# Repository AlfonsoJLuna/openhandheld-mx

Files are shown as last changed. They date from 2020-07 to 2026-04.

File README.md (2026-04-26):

# OpenHandheld MX

Open-source development board in the shape of a handheld game console.

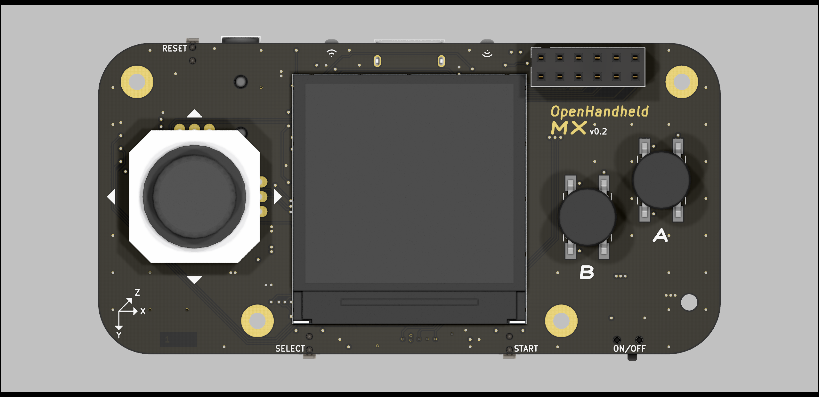
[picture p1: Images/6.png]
OpenHandheld MX (Front)
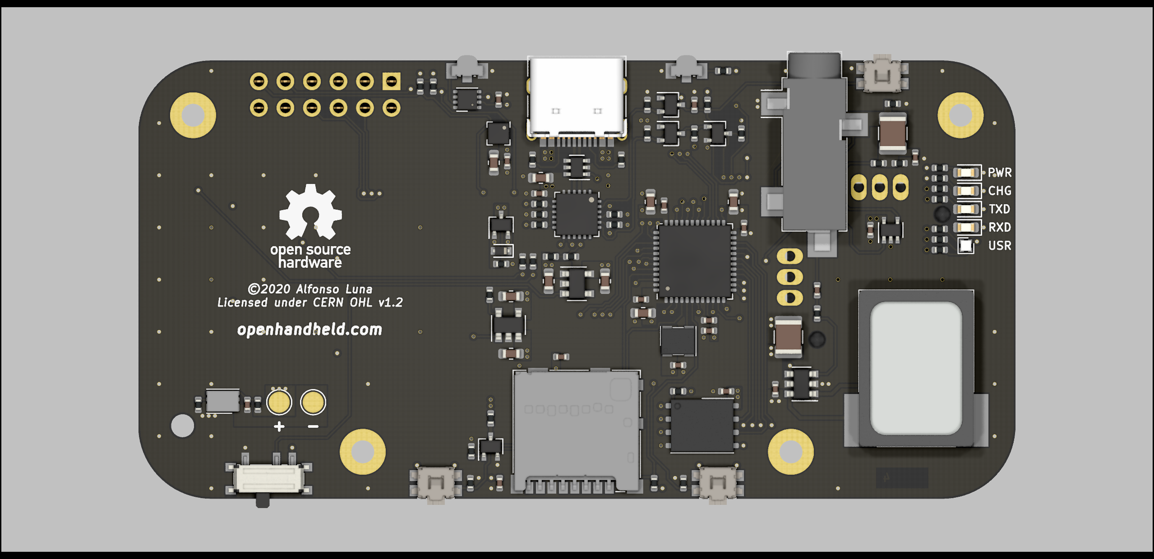
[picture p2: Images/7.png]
OpenHandheld MX (Back)
 | 
:---: | :---:
Front | Back

## Related repositories

Example code for this board can be found in [openhandheld-mx-sdk](https://github.com/AlfonsoJLuna/openhandheld-mx-sdk).

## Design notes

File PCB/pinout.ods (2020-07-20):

Número | Name | Header | Board | ADC | DAC | AF1/IR (TIM) | AF2 (TIM) | AF3 (USART2) | AF4 (I2C) | AF5 (SPI) | AF6 (SPI3) | AF7 (USARTS) | AF9 (CAN) | AF10 (QSPI) | AF14 (TIMS)
10 | PA0 | - | ADC VCC_DET | ADC1_IN5 |  | TIM2_CH1 | - | - | - | - | - | USART2_CTS | - | - | TIM2_ETR
11 | PA1 | - | LED B | ADC1_IN6 |  | TIM2_CH2 | - | - | I2C1_SMBA | SPI1_SCK | - | USART2_RTS_ DE | - | - | TIM15_CH1N
12 | PA2 | GPIO / ADC / USART2_TX | - | ADC1_IN7 |  | TIM2_CH3 | - | - | - | - | - | USART2_TX | - | QUADSPI_ BK1_NCS | TIM15_CH1
13 | PA3 | - | ADC JOY_Y | ADC1_IN8 |  | TIM2_CH4 | - | - | - | - | - | USART2_RX | - | QUADSPI_CLK | TIM15_CH2
14 | PA4 | - | ADC JOY_X | ADC1_IN9 | DAC1_OUT1 | - | - | - | - | SPI1_NSS | SPI3_NSS | USART2_CK | - | - | LPTIM2_OUT
15 | PA5 | - | AUDIO OUT | ADC1_IN10 | DAC1_OUT2 | TIM2_CH1 | TIM2_ETR | - | - | SPI1_SCK | - | - | - | - | LPTIM2_ETR
l | PA6 | - | QSPI_IO3 | ADC1_IN11 |  | TIM1_BKIN | - | - | - | SPI1_MISO | COMP1_OUT | USART3_CTS | - | QUADSPI_ BK1_IO3 | TIM16_CH1
17 | PA7 | - | QSPI_IO2 | ADC1_IN12 |  | TIM1_CH1N | - | - | I2C3_SCL | SPI1_MOSI | - | - | - | QUADSPI_ BK1_IO2 | -
29 | PA8 | - | LED R |  |  | TIM1_CH1 | - | - | - | - | - | USART1_CK | - | - | LPTIM2_OUT
30 | PA9 | - | USART1_TX |  |  | TIM1_CH2 | - | - | I2C1_SCL | - | - | USART1_TX | - | - | TIM15_BKIN
31 | PA10 | - | USART1_RX |  |  | TIM1_CH3 | - | - | I2C1_SDA | - | - | USART1_RX | - | - | -
32 | PA11 | - | LED G |  |  | TIM1_CH4 | TIM1_BKIN2 | - | - | SPI1_MISO | COMP1_OUT | USART1_CTS | CAN1_RX | - | -
33 | PA12 | - | LCD DATA/CMD |  |  | TIM1_ETR | - | - | - | SPI1_MOSI | - | USART1_RTS_DE | CAN1_TX | - | -
34 | PA13 (pull-up reset) | GPIO / SWDIO | - |  |  | IR_OUT | - | - | - | - | - | - | - | - | -
37 | PA14 (pull-down reset) | GPIO / SWCLK | - |  |  | LPTIM1_OUT | - | - | I2C1_SMBA | - | - | - | - | - | -
38 | PA15 (pull-up reset) | GPIO / USART2_RX | - |  |  | TIM2_CH1 | TIM2_ETR | USART2_RX | - | SPI1_NSS | SPI3_NSS | USART3_RTS_ DE | TSC_G3_IO1 |  | -
18 | PB0 | - | QSPI_IO1 | ADC1_IN15 |  | TIM1_CH2N | - | - | - | SPI1_NSS | - | USART3_CK | - | QUADSPI_ BK1_IO1 | -
19 | PB1 | - | QSPI_IO0 | ADC1_IN16 |  | TIM1_CH3N | - | - | - | - | - | USART3_RTS_DE | - | QUADSPI_ BK1_IO0 | LPTIM2_IN1
20 | PB2 | - | IR_IN |  |  | LPTIM1_OUT | - | - | I2C3_SMBA | - | - | - | - | - | -
39 | PB3 | - | LCD SCK |  |  | TIM2_CH2 | - | - | - | SPI1_SCK | SPI3_SCK | USART1_RTS_ DE | - | - | -
40 | PB4 (pull-up reset) | - | LCD RESET |  |  | - | - | - | I2C3_SDA | SPI1_MISO | SPI3_MISO | USART1_CTS | TSC_G2_IO1 | - | -
41 | PB5 | - | LCD MOSI |  |  | LPTIM1_IN1 | - | - | I2C1_SMBA | SPI1_MOSI | SPI3_MOSI | USART1_CK | TSC_G2_IO2 | - | TIM16_BKIN
42 | PB6 | I2C1_SCL | I2C1_SCL |  |  | LPTIM1_ETR | - | - | I2C1_SCL | - | - | USART1_TX | TSC_G2_IO3 | - | TIM16_CH1N
43 | PB7 | I2C1_SDA | I2C1_SDA |  |  | LPTIM1_IN2 | - | - | I2C1_SDA | - | - | USART1_RX | TSC_G2_IO4 | - | -
45 | PB8 | - | LCD LIGHT |  |  | - | - | - | I2C1_SCL | - | - | - | CAN1_RX | - | TIM16_CH1
46 | PB9 | - | IR_OUT |  |  | IR_OUT | - | - | I2C1_SDA | SPI2_NSS | - | - | CAN1_TX | - | -
21 | PB10 | - | QSPI_CLK |  |  | TIM2_CH3 | - | - | I2C2_SCL | SPI2_SCK | - | USART3_TX | TSC_SYNC | QUADSPI_CLK | -
22 | PB11 | - | QSPI_NCS |  |  | TIM2_CH4 | - | - | I2C2_SDA | - | - | USART3_RX | - | QUADSPI_ BK1_NCS | -
25 | PB12 |  | microSD CS |  |  | TIM1_BKIN | - | TIM1_BKIN_ COMP2 | I2C2_SMBA | SPI2_NSS | - | USART3_CK | TSC_G1_IO1 | - | TIM15_BKIN
26 | PB13 | SPI2_SCK | microSD SCK |  |  | TIM1_CH1N | - | - | I2C2_SCL | SPI2_SCK | - | USART3_CTS | TSC_G1_IO2 | - | TIM15_CH1N
27 | PB14 | SPI2_MISO | microSD MISO |  |  | TIM1_CH2N | - | - | I2C2_SDA | SPI2_MISO | - | USART3_RTS_ DE | TSC_G1_IO3 | - | TIM15_CH1
28 | PB15 | SPI2_MOSI | microSD MOSI |  |  | TIM1_CH3N | - | - | - | SPI2_MOSI | - | - | TSC_G1_IO4 | - | TIM15_CH2
2 | PC13 | - | B
3 | PC14-OSC32_IN | - | A
4 | PC15-OSC32_OUT | - | START
6 | PH1-OSC_OUT | - | SELECT
1 | VBAT
5 | PH0-OSC_IN
7 | NRST | RESET | RESET
8 | VSSA/VREF-
9 | VDDA/VREF+
23 | GND
24 | VDD
35 | GND
36 | VDD | 3V3
44 | PH3/BOOT0 |  | BOOT0
47 | GND | GND
48 | VDD
49 | PAD

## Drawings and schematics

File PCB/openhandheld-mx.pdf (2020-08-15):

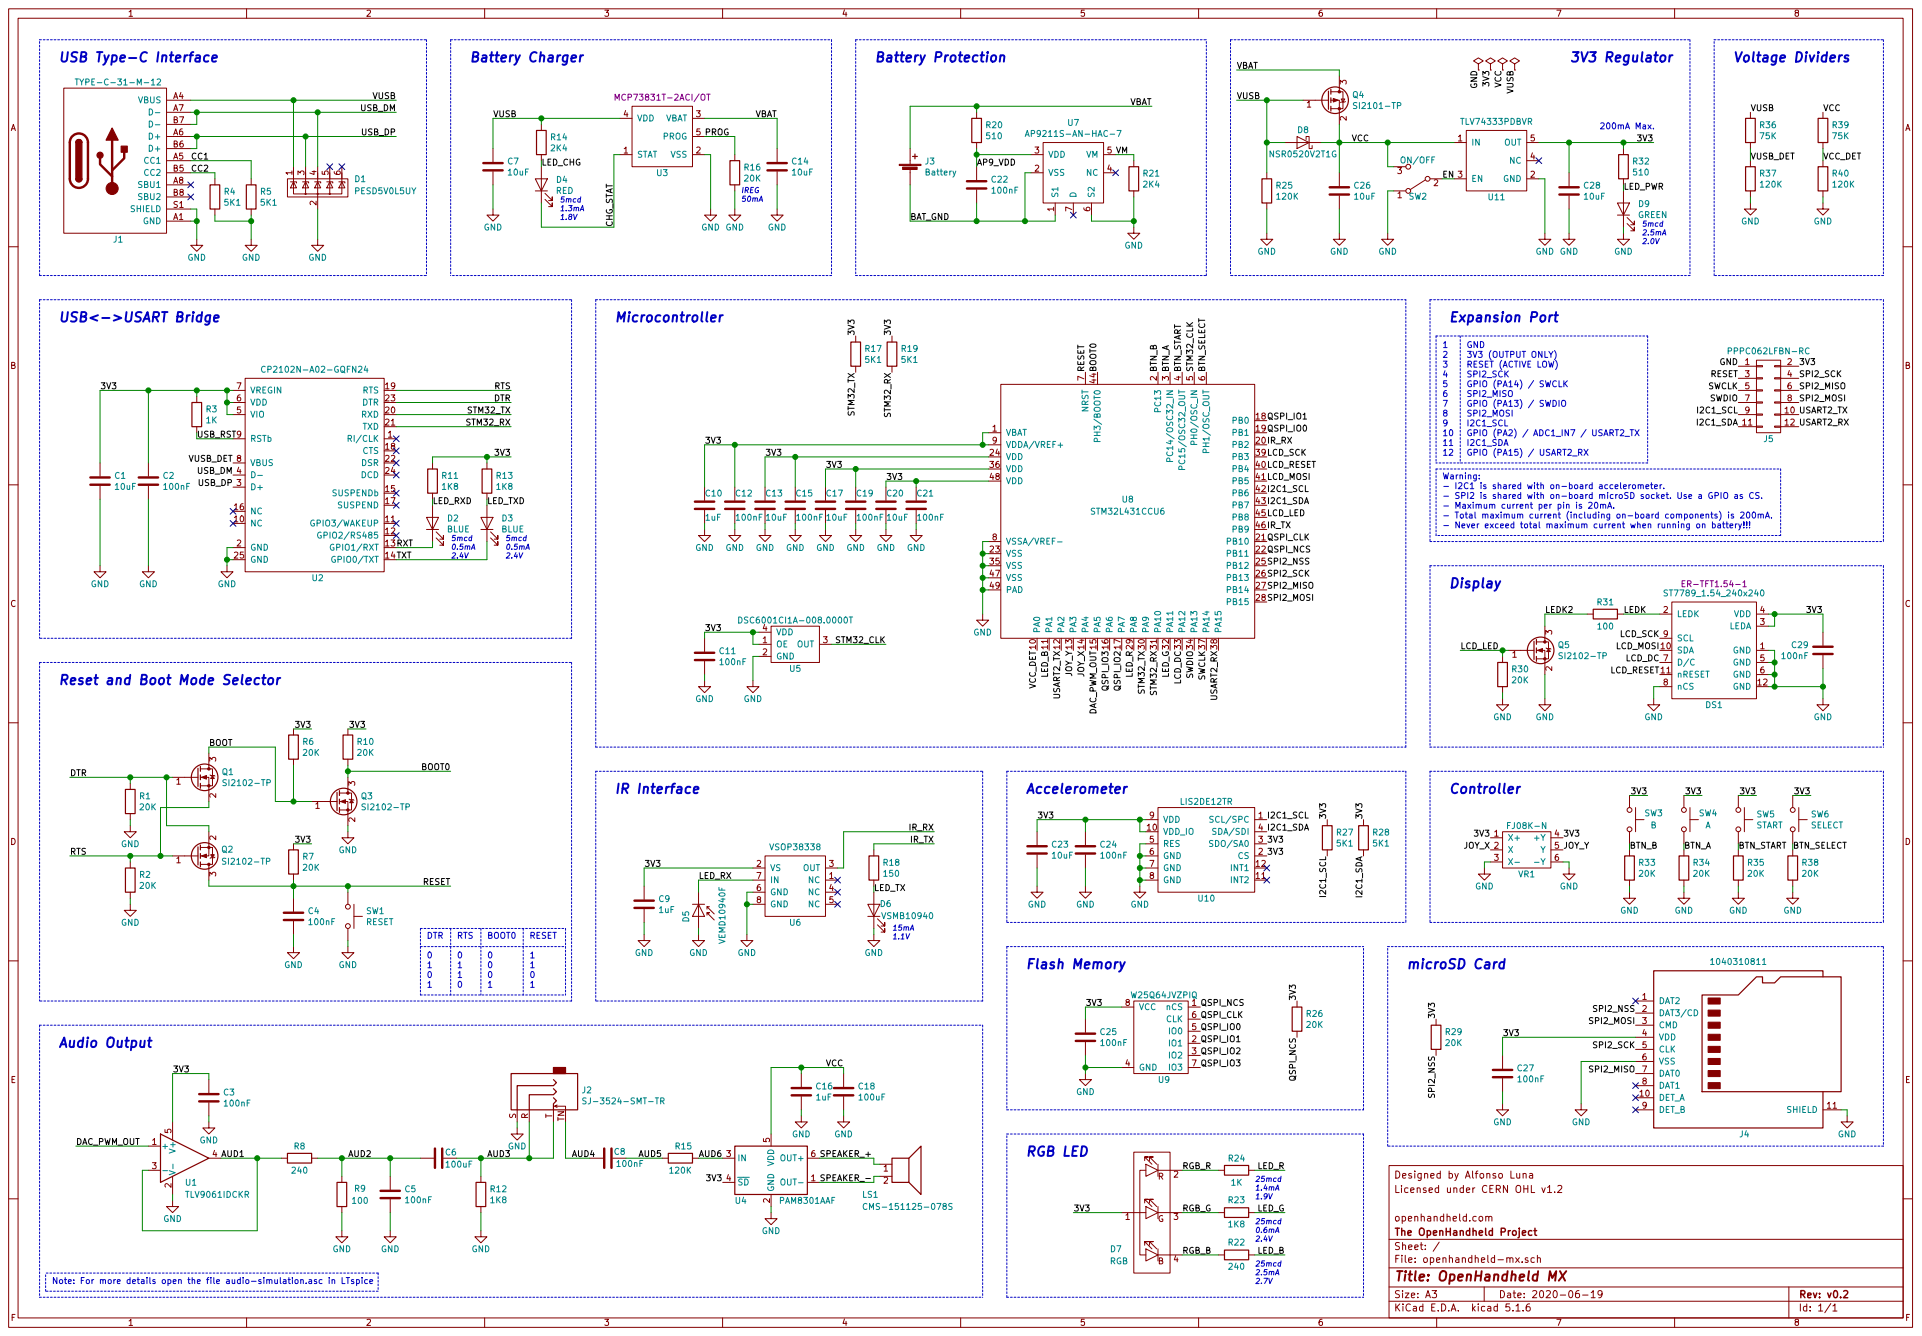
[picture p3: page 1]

200mA Max. Reset and Boot Mode Selector

1 VSS 2 VDD 3 NC 4 VM 5 S2

Expansion Port 1

- Never exceed total maximum current when running on battery!!! GND

2 3 4 5 6 7 8 9 10 11 | 3V3 (OUTPUT ONLY) RESET (ACTIVE LOW) SPI2_SCK GPIO (PA14) / SWCLK SPI2_MISO GPIO (PA13) / SWDIO SPI2_MOSI I2C1_SCL GPIO (PA2) / ADC1_IN7 / USART2_TX I2C1_SDA GPIO (PA15) / USART2_RX

7 VSSA/VREF- 8 VDDA/VREF+ 9 U8 STM32L431CCU6 C11

12Warning: - I2C1 is shared with on-board accelerometer. - SPI2 is shared with on-board microSD socket. Use a GPIO as CS. - Maximum current per pin is 20mA.

- Total maximum current (including on-board components) is 200mA.

Licensed under CERN OHL v1.2 Designed by Alfonso Luna

openhandheld.com
File: openhandheld-mx.sch Sheet: / The OpenHandheld Project

Id: 1/1 Title: OpenHandheld MX

Note: For more details open the file audio-simulation.asc in LTspice

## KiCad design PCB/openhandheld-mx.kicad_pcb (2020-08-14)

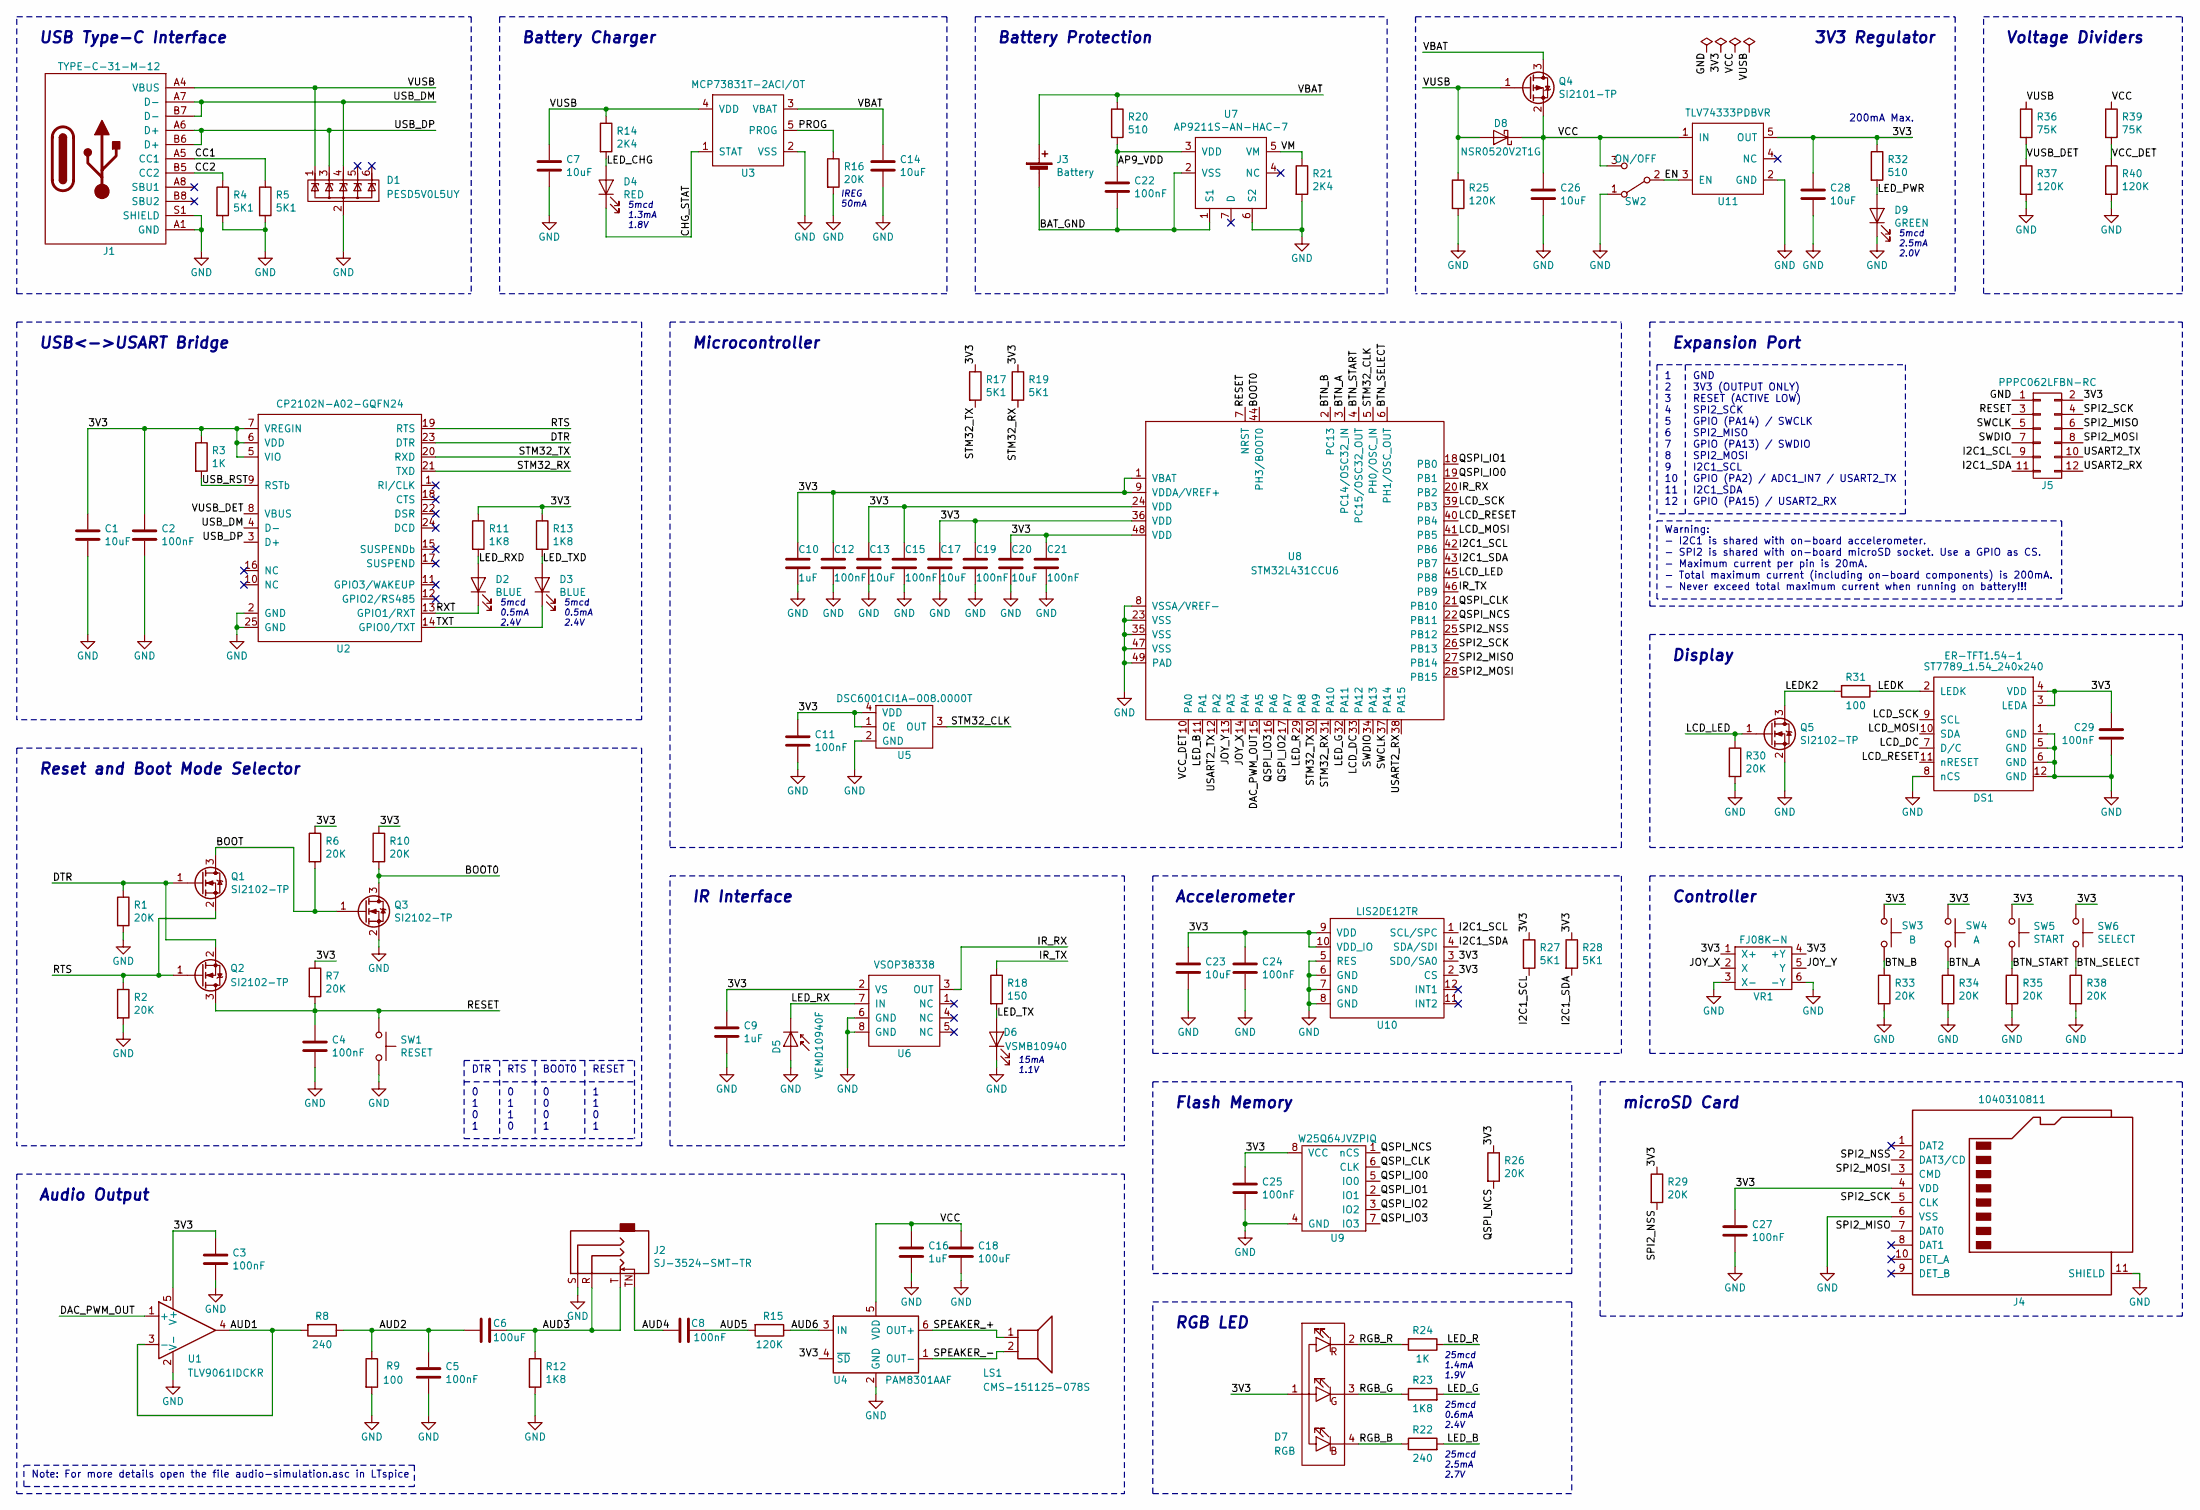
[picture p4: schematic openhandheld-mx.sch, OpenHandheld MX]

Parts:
C1, C7, C13, C14, C17, C20, C23, C26, C28: 10uF; C_0603_1608Metric; MPN CL10A106KP8NNNC
C2, C3, C4, C5, C8, C11, C12, C15, C19, C21, C22, C24, C25, C27, C29: 100nF; C_0402_1005Metric; MPN CL05B104KO5NNNC
C6, C18: 100uF; C_1210_3225Metric; MPN CL32A107MQVNNNE
C9, C10, C16: 1uF; C_0402_1005Metric; MPN CL05A105KO5NNNC
D1: PESD5V0L5UY; SOT-363_SC-70-6; MPN PESD5V0L5UY
D2, D3: BLUE; LED_0603_1608Metric; MPN 150060BS75000
D4: RED; LED_0603_1608Metric; MPN 150060SS75000
D5: VEMD10940F; Vishay_IR; MPN VEMD10940F
D6: VSMB10940; Vishay_IR; MPN VSMB10940
D7: RGB; 150044M155260; MPN 150044M155260
D8: NSR0520V2T1G; D_SOD-523; MPN NSR0520V2T1G
D9: GREEN; LED_0603_1608Metric; MPN 150060VS75000
DS1: ST7789_1.54_240x240; MPN ER-TFT1.54-1
J1: TYPE-C-31-M-12; MPN TYPE-C-31-M-12
J2: SJ-3524-SMT-TR; MPN SJ-3524-SMT-TR
J3: Battery; Solder_Pad_D2
J4: 1040310811; MPN 1040310811
J5: PPPC062LFBN-RC; PinSocket_2x06_P2.54mm_Vertical; MPN PPPC062LFBN-RC
LS1: CMS-151125-078S; Speaker_15x11mm; MPN CMS-151125-078S
Q1, Q2, Q3, Q5: SI2102-TP; SOT-323_SC-70; MPN SI2102-TP
Q4: SI2101-TP; SOT-323_SC-70; MPN SI2101-TP
R1, R2, R6, R7, R10, R16, R26, R29, R30, R33, R34, R35, R38: 20K; R_0402_1005Metric; MPN RC0402FR-0720KL
R3, R24: 1K; R_0402_1005Metric; MPN RC0402FR-071KL
R4, R5, R17, R19, R27, R28: 5K1; R_0402_1005Metric; MPN RC0402FR-075K1L
R8, R22: 240; R_0402_1005Metric; MPN RC0402FR-07240RL
R9, R31: 100; R_0402_1005Metric; MPN RC0402FR-07100RL
R11, R12, R13, R23: 1K8; R_0402_1005Metric; MPN RC0402FR-071K8L
R14, R21: 2K4; R_0402_1005Metric; MPN RC0402FR-072K4L
R15, R25, R37, R40: 120K; R_0402_1005Metric; MPN RC0402FR-07120KL
R18: 150; R_0402_1005Metric; MPN RC0402FR-07150RL
R20, R32: 510; R_0402_1005Metric; MPN RC0402FR-07510RL
R36, R39: 75K; R_0402_1005Metric; MPN RC0402FR-0775KL
SW1: RESET; EVQP7; MPN EVQ-P7L01P
SW2: ON/OFF; CUS-12TB; MPN CUS-12TB
SW3: B; TL3301TF160QG; MPN TL3301TF160QG
SW4: A; TL3301TF160QG; MPN TL3301TF160QG
SW5: START; EVQP7; MPN EVQ-P7L01P
SW6: SELECT; EVQP7; MPN EVQ-P7L01P
U1: TLV9061IDCKR; SOT-353_SC-70-5; MPN TLV9061IDCKR
U2: CP2102N-A02-GQFN24; QFN-24-1EP_4x4mm_P0.5mm_EP2.6x2.6mm; MPN CP2102N-A02-GQFN24
U3: MCP73831T-2ACI_OT; SOT-23-5; MPN MCP73831T-2ACI/OT
U4: PAM8301AAF; SOT-23-6; MPN PAM8301AAF
U5: DSC6001CI1A-008.0000T; DSC60XX-3.2x2.5; MPN DSC6001CI1A-008.0000T
U6: VSOP38338; MPN VSOP38338
U7: AP9211S-AN-HAC-7; MPN AP9211S-AN-HAC-7
U8: STM32L431CCU6; STM32-UFQFPN48; MPN STM32L431CCU6
U9: W25Q64JVZPIQ; Winbond_WSON8_6x5mm; MPN W25Q64JVZPIQ
U10: LIS2DE12TR; MPN LIS2DE12TR
U11: TLV74333PDBVR; SOT-23-5; MPN TLV74333PDBVR
VR1: FJ08K-N; MPN FJ08K-N

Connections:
/3V3: C1.1, C2.1, C3.1, C9.1, C10.1, C11.1, C12.1, C13.1, C15.1, C17.1, C19.1, C20.1, C21.1, C23.1, C24.1, C25.1, C27.1, C28.1, C29.1, D7.1 (A), DS1.3 (LEDA), DS1.4 (VDD), J4.4 (VDD), J5.2, R3.1, R6.1, R7.1, R10.1, R11.1, R13.1, R17.1, R19.1, R26.1, R27.1, R28.1, R29.1, R32.1, SW3.2, SW4.2, SW5.1, SW6.1, U1.5 (V+), U2.5 (VIO), U2.6 (VDD), U2.7 (VREGIN), U4.4 (~SD), U5.1 (OE), U5.4 (VDD), U6.2 (VS), U8.1 (VBAT), U8.9 (VDDA/VREF+), U8.24 (VDD), U8.36 (VDD), U8.48 (VDD), U9.8 (VCC), U10.2 (CS), U10.3 (SDO/SA0), U10.9 (VDD), U10.10 (VDD_IO), U11.5 (OUT), VR1.1 (X+), VR1.4 (+Y)
/AP9_VDD: C22.1, R20.2, U7.3 (VDD)
/AUD1: R8.2, U1.3 (-), U1.4
/AUD2: C5.1, C6.2, R8.1, R9.1
/AUD3: C6.1, J2.R, J2.T, R12.1
/AUD4: C8.1, J2.TN
/AUD5: C8.2, R15.2
/AUD6: R15.1, U4.3 (IN)
/BAT_GND: C22.2, J3.2 (-), U7.1 (S1), U7.2 (VSS)
/BOOT: Q1.3 (D), Q3.1 (G), R6.2
/BOOT0: Q3.3 (D), R10.2, U8.44 (PH3/BOOT0)
/BTN_A: R34.1, SW4.1, U8.3 (PC14/OSC32_IN)
/BTN_B: R33.1, SW3.1, U8.2 (PC13)
/BTN_SELECT: R38.1, SW6.2, U8.6 (PH1/OSC_OUT)
/BTN_START: R35.1, SW5.2, U8.4 (PC15/OSC32_OUT)
/CC1: J1.A5 (CC1), R5.1
/CC2: J1.B5 (CC2), R4.1
/CHG_STAT: D4.1 (K), U3.1 (STAT)
/DAC_PWM_OUT: U1.1 (+), U8.15 (PA5)
/DTR: Q1.1 (G), Q2.2 (S), R1.1, U2.23 (DTR)
/EN: SW2.2 (B), U11.3 (EN)
/I2C1_SCL: J5.9, R27.2, U8.42 (PB6), U10.1 (SCL/SPC)
/I2C1_SDA: J5.11, R28.2, U8.43 (PB7), U10.4 (SDA/SDI)
/IR_RX: U6.3 (OUT), U8.20 (PB2)
/IR_TX: R18.1, U8.46 (PB9)
/JOY_X: U8.14 (PA4), VR1.2 (X)
/JOY_Y: U8.13 (PA3), VR1.5 (Y)
/LCD_DC: DS1.7 (D/C), U8.33 (PA12)
/LCD_LED: Q5.1 (G), R30.1, U8.45 (PB8)
/LCD_MOSI: DS1.10 (SDA), U8.41 (PB5)
/LCD_RESET: DS1.11 (nRESET), U8.40 (PB4)
/LCD_SCK: DS1.9 (SCL), U8.39 (PB3)
/LEDK: DS1.2 (LEDK), R31.1
/LEDK2: Q5.3 (D), R31.2
/LED_B: R22.2, U8.11 (PA1)
/LED_CHG: D4.2 (A), R14.2
/LED_G: R23.2, U8.32 (PA11)
/LED_PWR: D9.2 (A), R32.2
/LED_R: R24.1, U8.29 (PA8)
/LED_RX: D5.1 (K), U6.7 (IN)
/LED_RXD: D2.2 (A), R11.2
/LED_TX: D6.2 (A), R18.2
/LED_TXD: D3.2 (A), R13.2
/PROG: R16.1, U3.5 (PROG)
/QSPI_CLK: U8.21 (PB10), U9.6 (CLK)
/QSPI_IO0: U8.19 (PB1), U9.5 (IO0)
/QSPI_IO1: U8.18 (PB0), U9.2 (IO1)
/QSPI_IO2: U8.17 (PA7), U9.3 (IO2)
/QSPI_IO3: U8.16 (PA6), U9.7 (IO3)
/QSPI_NCS: R26.2, U8.22 (PB11), U9.1 (nCS)
/RESET: C4.1, J5.3, Q2.3 (D), R7.2, SW1.1, U8.7 (NRST)
/RGB_B: D7.4 (BK), R22.1
/RGB_G: D7.3 (GK), R23.1
/RGB_R: D7.2 (RK), R24.2
/RTS: Q1.2 (S), Q2.1 (G), R2.1, U2.19 (RTS)
/RXT: D2.1 (K), U2.13 (GPIO1/RXT)
/SPEAKER_+: LS1.1, U4.6 (OUT+)
/SPEAKER_-: LS1.2, U4.1 (OUT-)
/SPI2_MISO: J4.7 (DAT0), J5.6, U8.27 (PB14)
/SPI2_MOSI: J4.3 (CMD), J5.8, U8.28 (PB15)
/SPI2_NSS: J4.2 (DAT3/CD), R29.2, U8.25 (PB12)
/SPI2_SCK: J4.5 (CLK), J5.4, U8.26 (PB13)
/STM32_CLK: U5.3 (OUT), U8.5 (PH0/OSC_IN)
/STM32_RX: R19.2, U2.21 (TXD), U8.31 (PA10)
/STM32_TX: R17.2, U2.20 (RXD), U8.30 (PA9)
/SWCLK: J5.5, U8.37 (PA14)
/SWDIO: J5.7, U8.34 (PA13)
/TXT: D3.1 (K), U2.14 (GPIO0/TXT)
/USART2_RX: J5.12, U8.38 (PA15)
/USART2_TX: J5.10, U8.12 (PA2)
/USB_DM: D1.4 (IO3), J1.A7 (D-), J1.B7 (D-), U2.4 (D-)
/USB_DP: D1.3 (IO2), J1.A6 (D+), J1.B6 (D+), U2.3 (D+)
/USB_RST: R3.2, U2.9 (RSTb)
/VBAT: C14.1, J3.1 (+), Q4.3 (D), R20.1, U3.3 (VBAT)
/VCC: C16.1, C18.1, C26.1, D8.1 (K), Q4.2 (S), R39.1, SW2.3 (C), U4.5 (VDD), U11.1 (IN)
/VCC_DET: R39.2, R40.1, U8.10 (PA0)
/VM: R21.1, U7.5 (VM)
/VUSB: C7.1, D1.1 (IO1), D8.2 (A), J1.A4 (VBUS), J1.A9 (VBUS), J1.B4 (VBUS), J1.B9 (VBUS), Q4.1 (G), R14.1, R25.1, R36.1, U3.4 (VDD)
/VUSB_DET: R36.2, R37.1, U2.8 (VBUS)
GND: C1.2, C2.2, C3.2, C4.2, C5.2, C7.2, C9.2, C10.2, C11.2, C12.2, C13.2, C14.2, C15.2, C16.2, C17.2, C18.2, C19.2, C20.2, C21.2, C23.2, C24.2, C25.2, C26.2, C27.2, C28.2, C29.2, D1.2 (GND), D5.2 (A), D6.1 (K), D9.1 (K), DS1.1 (GND), DS1.5 (GND), DS1.6 (GND), DS1.8 (nCS), DS1.12 (GND), J1.A1 (GND), J1.A12 (GND), J1.B1 (GND), J1.B12 (GND), J1.S1 (SHIELD), J2.S, J4.6 (VSS), J4.11 (SHIELD), J5.1, Q3.2 (S), Q5.2 (S), R1.2, R2.2, R4.2, R5.2, R9.2, R12.2, R16.2, R21.2, R25.2, R30.2, R33.2, R34.2, R35.2, R37.2, R38.2, R40.2, SW1.2, SW2.1 (A), U1.2 (V-), U2.2 (GND), U2.25 (GND), U3.2 (VSS), U4.2 (GND), U5.2 (GND), U6.6 (GND), U6.8 (GND), U7.6 (S2), U8.8 (VSSA/VREF-), U8.23 (VSS), U8.35 (VSS), U8.47 (VSS), U8.49 (PAD), U9.4 (GND), U10.5 (RES), U10.6 (GND), U10.7 (GND), U10.8 (GND), U11.2 (GND), VR1.3 (X-), VR1.6 (-Y)

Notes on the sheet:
Battery Charger
Battery Protection
IREG 50mA
5mcd 2.5mA 2.0V
3V3 Regulator
5mcd 1.3mA 1.8V
Voltage Dividers
200mA Max.
Reset and Boot Mode Selector
5mcd 0.5mA 2.4V
USB<->USART Bridge
USB Type-C Interface
Expansion Port
1 2 3 4 5 6 7 8 9 10 11 12
Warning: - I2C1 is shared with on-board accelerometer. - SPI2 is shared with on-board microSD socket. Use a GPIO as CS. - Maximum current per pin is 20mA. - Total maximum current (including on-board components) is 200mA. - Never exceed total maximum current when running on battery!!!
GND 3V3 (OUTPUT ONLY) RESET (ACTIVE LOW) SPI2_SCK GPIO (PA14) / SWCLK SPI2_MISO GPIO (PA13) / SWDIO SPI2_MOSI I2C1_SCL GPIO (PA2) / ADC1_IN7 / USART2_TX I2C1_SDA GPIO (PA15) / USART2_RX
Display
microSD Card
Controller
Audio Output
Note: For more details open the file audio-simulation.asc in LTspice
IR Interface
15mA 1.1V
Accelerometer
25mcd 2.5mA 2.7V
25mcd 1.4mA 1.9V
25mcd 0.6mA 2.4V
RGB LED
Flash Memory
Microcontroller
DTR 0 1 0 1
RESET 1 1 0 1
BOOT0 0 0 0 1
RTS 0 1 1 0

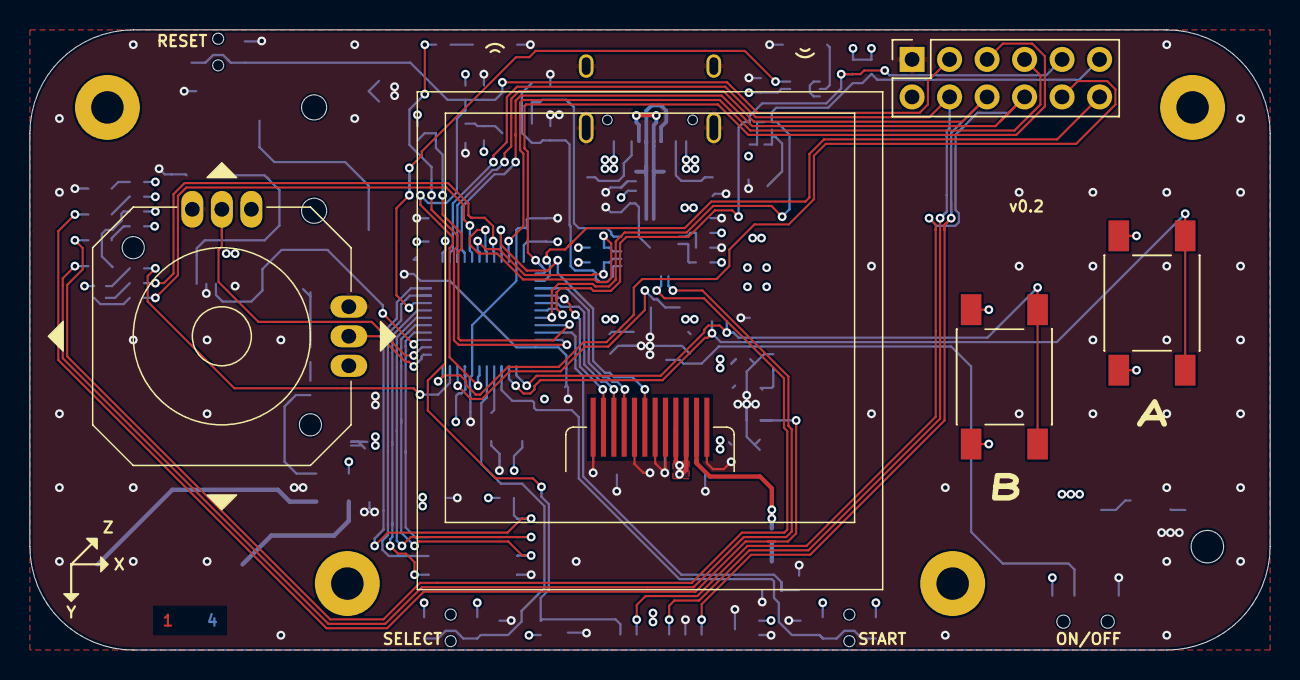
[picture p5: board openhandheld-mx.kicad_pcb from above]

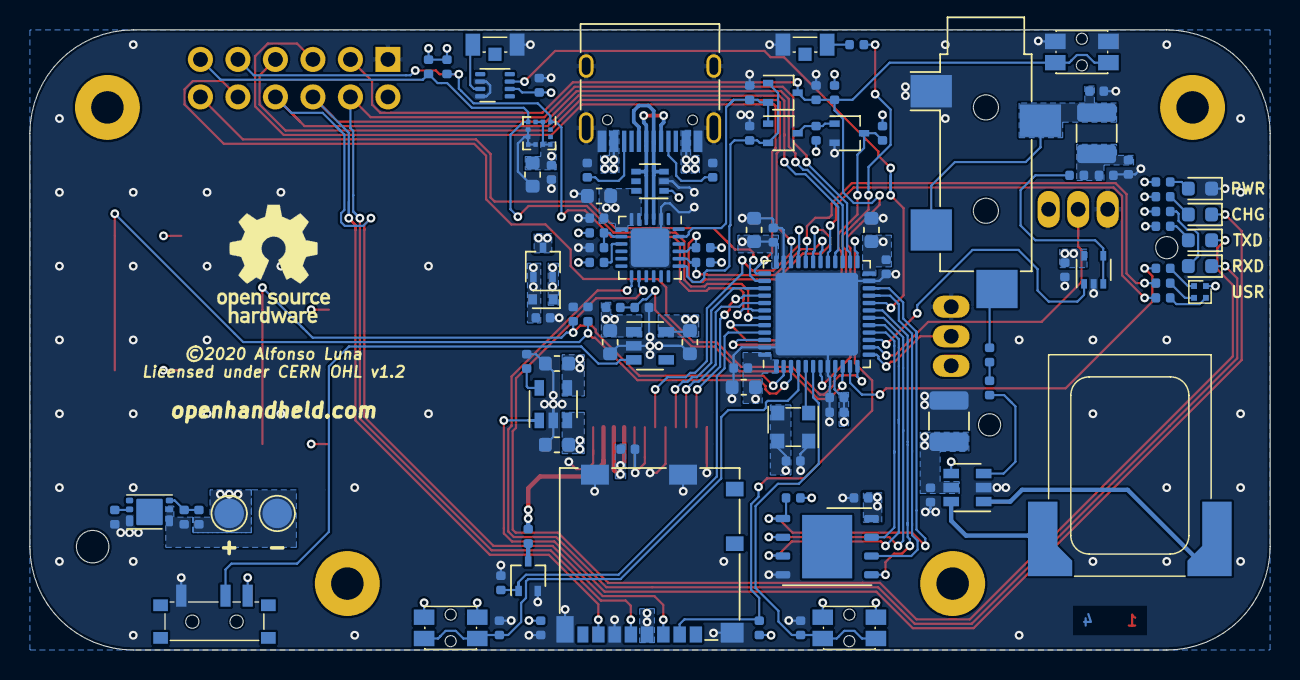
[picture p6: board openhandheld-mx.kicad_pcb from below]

Board: 4 copper layers, 84.0 x 42.0 mm, 108 parts (103 on the bottom side), 80 nets.

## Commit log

2020-03-25 Added v0.1
    [openhandheld-mx.kicad_pcb, openhandheld-mx.sch]
2020-03-26 Case v0.2: Improved dimensions
2020-04-26 PCB v0.2: Completed schematic
    [openhandheld-mx.kicad_pcb, openhandheld-mx.sch]
2020-06-17 PCB v0.2: Reduced component dimensions. Preliminary placement
    [openhandheld-mx.kicad_pcb, openhandheld-mx.sch, pinout.ods]
2020-06-21 PCB v0.2: Starting to route
    [openhandheld-mx.kicad_pcb, openhandheld-mx.sch]
2020-06-28 PCB v0.2: Finished placement, created power planes
    [openhandheld-mx.kicad_pcb, openhandheld-mx.sch]
2020-07-11 PCB v0.2: Power planes
    [openhandheld-mx.kicad_pcb]
2020-07-18 PCB v0.2: STM32 fanout
    [openhandheld-mx.kicad_pcb, openhandheld-mx.sch, pinout.ods]
2020-07-18 PCB v0.2: Finished placement. Routing...
    [openhandheld-mx.kicad_pcb]
2020-07-19 PCB v0.2: Finished routing.
    [openhandheld-mx.kicad_pcb]
2020-07-20 PCB v0.2: Silkscreen.
    [openhandheld-mx.kicad_pcb, openhandheld-mx.sch, pinout.ods]
2020-08-14 Case v0.2: Finished
    [openhandheld-mx.kicad_pcb, openhandheld-mx.sch]
2020-08-15 PCB v0.2: Added pdf schematic and pcb renders
2026-04-26 Removed v0.1 files as now there is a dedicated tag
    [openhandheld-mx.kicad_pcb, openhandheld-mx.sch, pinout.ods]
2026-04-26 Deleted firmware folder as now it lives in a different repo
    [openhandheld-mx.kicad_pcb, openhandheld-mx.sch, pinout.ods]
2026-04-26 Added SVG case files

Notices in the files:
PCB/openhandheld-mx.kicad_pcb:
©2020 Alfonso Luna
